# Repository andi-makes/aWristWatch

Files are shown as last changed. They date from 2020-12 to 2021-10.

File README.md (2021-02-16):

# andi makes a wrist watch! ⌚
> *It ain't pretty, but it's **mine**!* 😄

## Hardware 💡
### Microcontroller
The microcontroller used by this project is the `STM32L011F4` from STM. 
It features many peripherals as well as low power operation features.

### Display
This watch displays the time using four `KCSA02-105` 7-Segment displays from 
Kingbright. They were chosen because of their small footprint. Those 7-Segment 
displays are driven by the `STP08DP05` serial constant current driver from STM.

### Power
In it's normal operation, the watch gets powered by a LIPO battery. It can also 
be powered by an external powersource which provides 5V. The external connection
is also used to charge the internal LIPO using a `MCP73831` charger IC from 
Microchip. For OR-ing those two power supplies together so that the battery
is not used for powering the circuit during charging two `LM66100` ideal diodes
are used. The resulting powerline gets regulated by a `TLV70033` linear voltage 
regulator. The resulting 3.3V are used to power the microcontroller. For the 
powersupply for the display the non regulated voltage is used.

## Firmware 🧠

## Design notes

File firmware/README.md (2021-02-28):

# About
I am using the following tools:
 - docker
 - arm-none-eabi-gcc
 - cmake and ccmake
 - ninja build system
 - cppcheck

`C++20` is the used `C++` standard.

# Build
```
[c]cmake -G Ninja -DCMAKE_TOOLCHAIN_FILE=cmake/toolchain.cmake PROJECTDIR
```
The resulting binary files will be located in the `bin` folder.

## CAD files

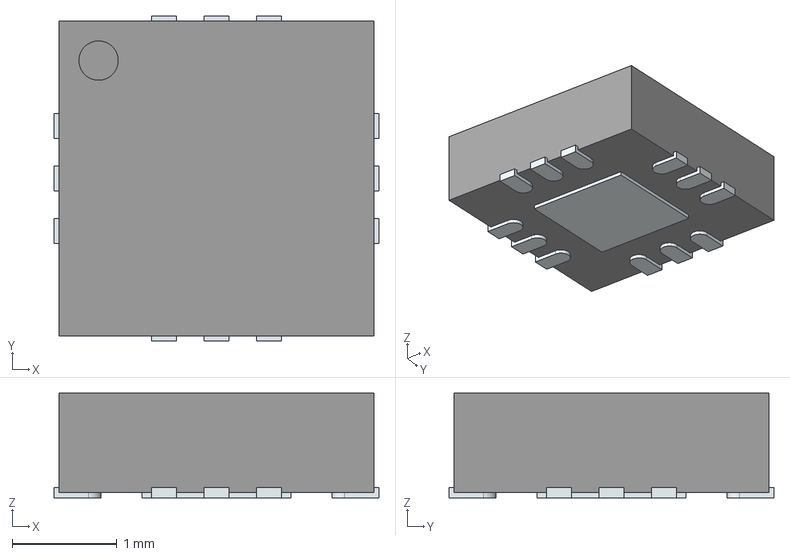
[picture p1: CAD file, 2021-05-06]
hardware/3dmodels/TCPP01-M12.stp
3.10 x 3.10 x 1.00 mm
ThermalPin
PinsArrayLR
PinsArrayTB

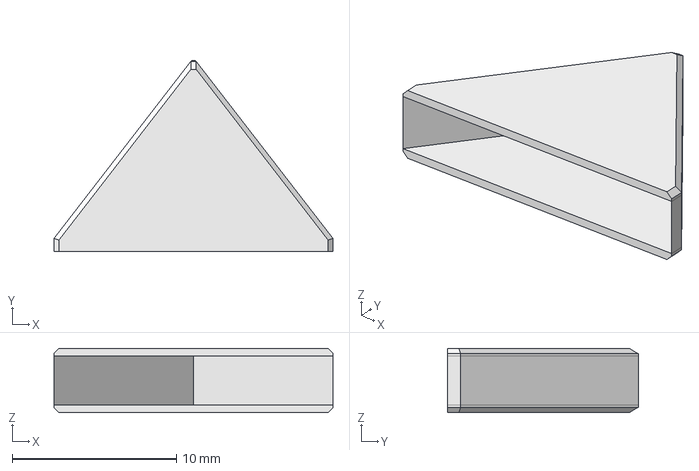
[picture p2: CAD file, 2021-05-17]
model/wristband_endcap.FCStd
17.0 x 11.6 x 3.90 mm

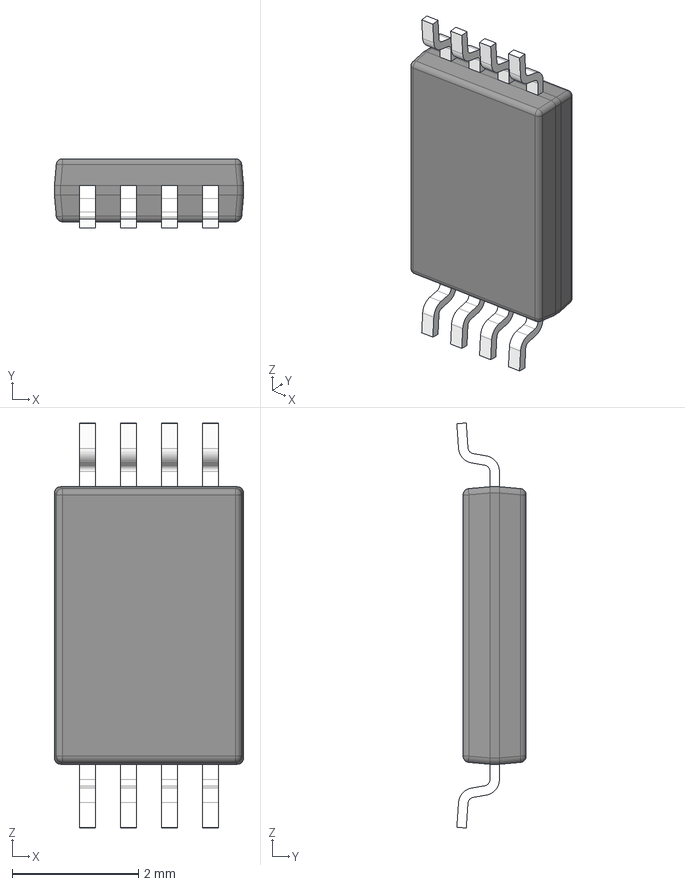
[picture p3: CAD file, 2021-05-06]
hardware/3dmodels/PW0008A.stp
3.00 x 1.10 x 6.42 mm
BODY-SO
LEAD-SO x 8
PIN1-ID

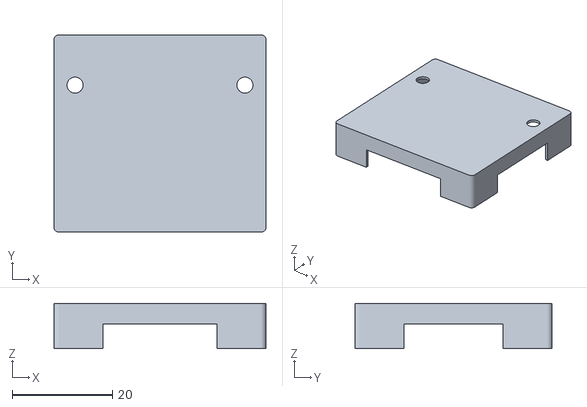
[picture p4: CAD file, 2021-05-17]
model/upper_no_prog.stl
42.3 x 39.4 x 9.00

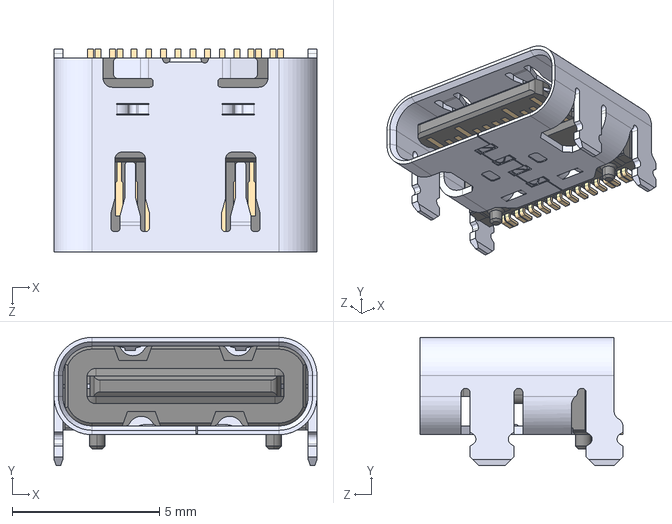
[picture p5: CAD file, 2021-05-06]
hardware/3dmodels/DX07S016JA1R1500--3DModel-STEP-1.STEP
8.94 x 4.36 x 6.90 mm

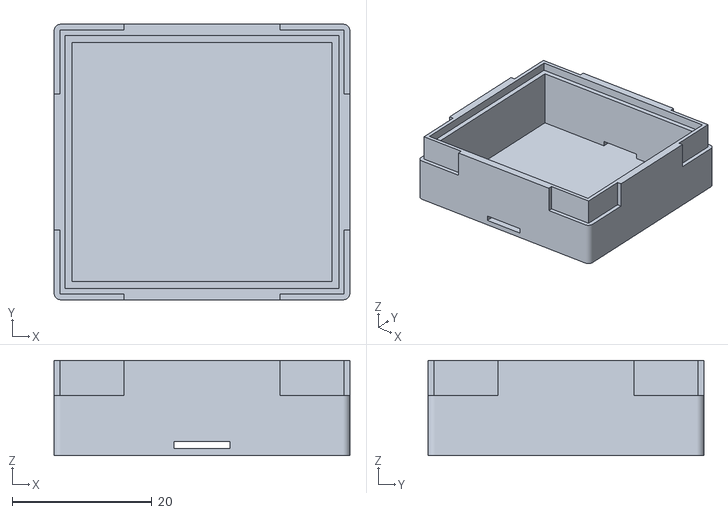
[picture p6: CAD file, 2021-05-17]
model/lower.stl
42.3 x 39.4 x 13.6

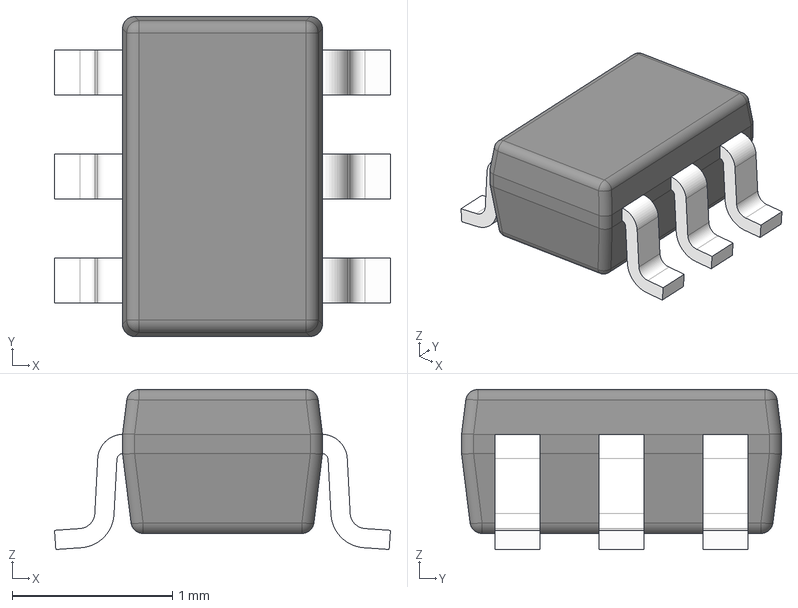
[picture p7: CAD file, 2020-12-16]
hardware/3dmodels/DCK0006A.stp
2.10 x 2.00 x 1.00 mm
BODY-SOT
LEAD-SOT x 6
PIN1-ID

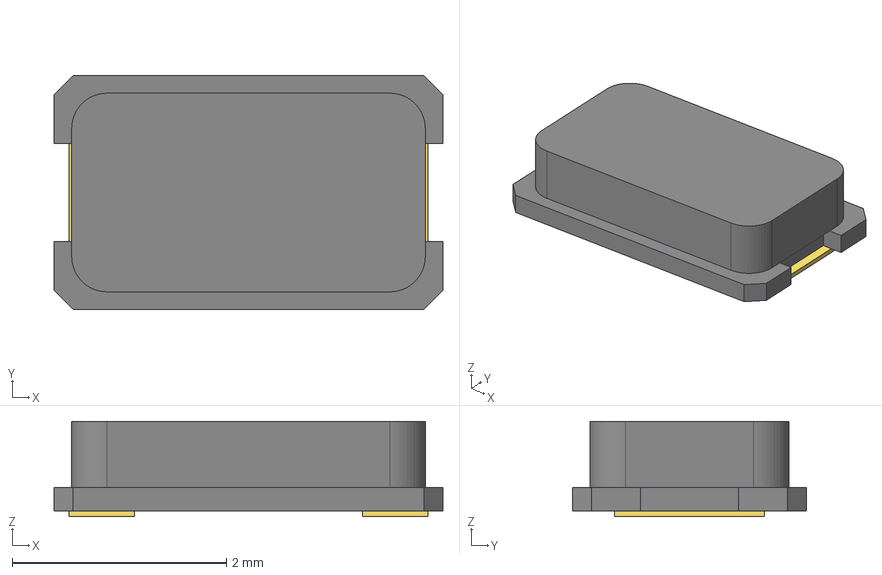
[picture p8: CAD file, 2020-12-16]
hardware/3dmodels/XTAL_ABS07-166-32_768KHZ-T_ABR.step
3.63 x 2.18 x 0.889 mm

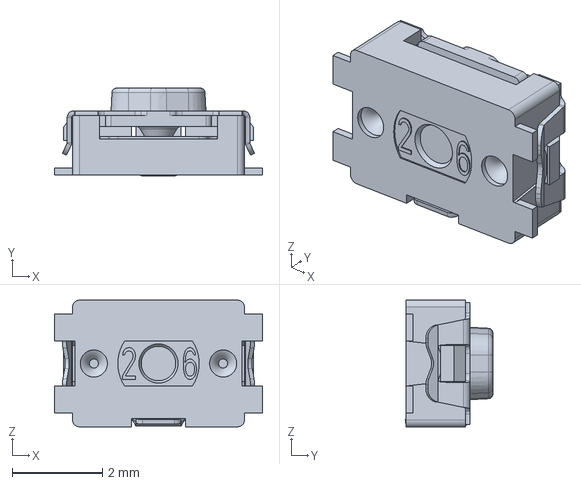
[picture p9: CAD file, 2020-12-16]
hardware/3dmodels/KMR211GLFS.stp
4.60 x 1.94 x 2.80 mm

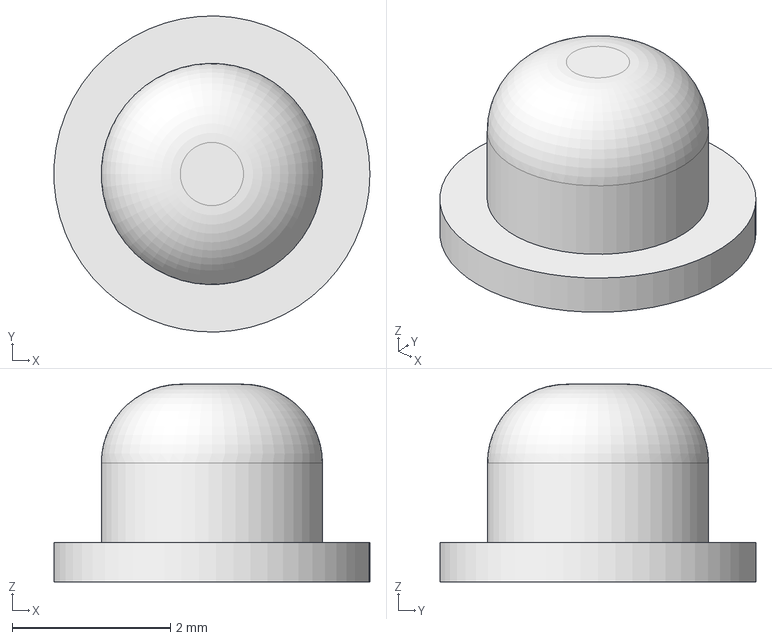
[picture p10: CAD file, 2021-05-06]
model/button.FCStd
4.00 x 4.00 x 2.50 mm

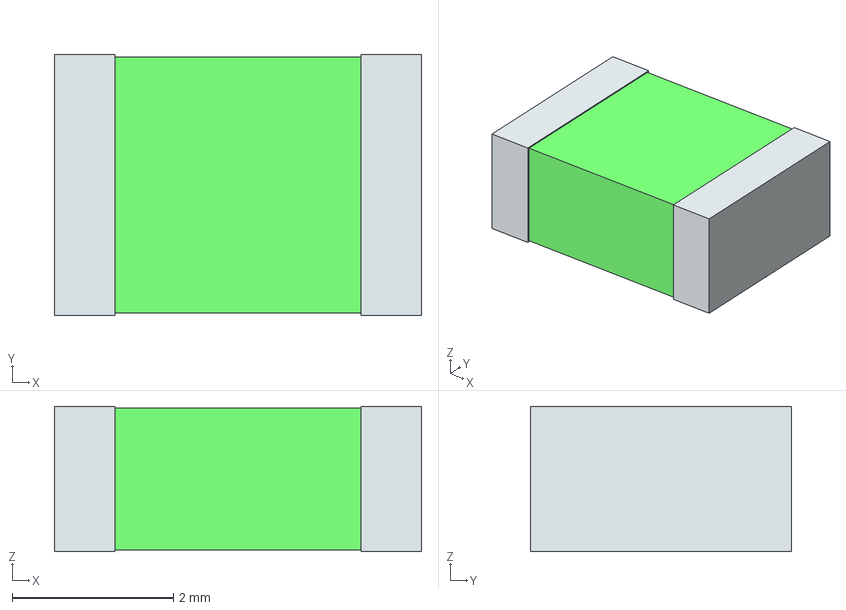
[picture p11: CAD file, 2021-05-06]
hardware/3dmodels/1812L050_60MR.stp
4.55 x 3.24 x 1.80 mm
term1
term2

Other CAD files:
model/wristband_endcap-cap.stl
model/case.FCStd
model/upper.stl
model/button.stl

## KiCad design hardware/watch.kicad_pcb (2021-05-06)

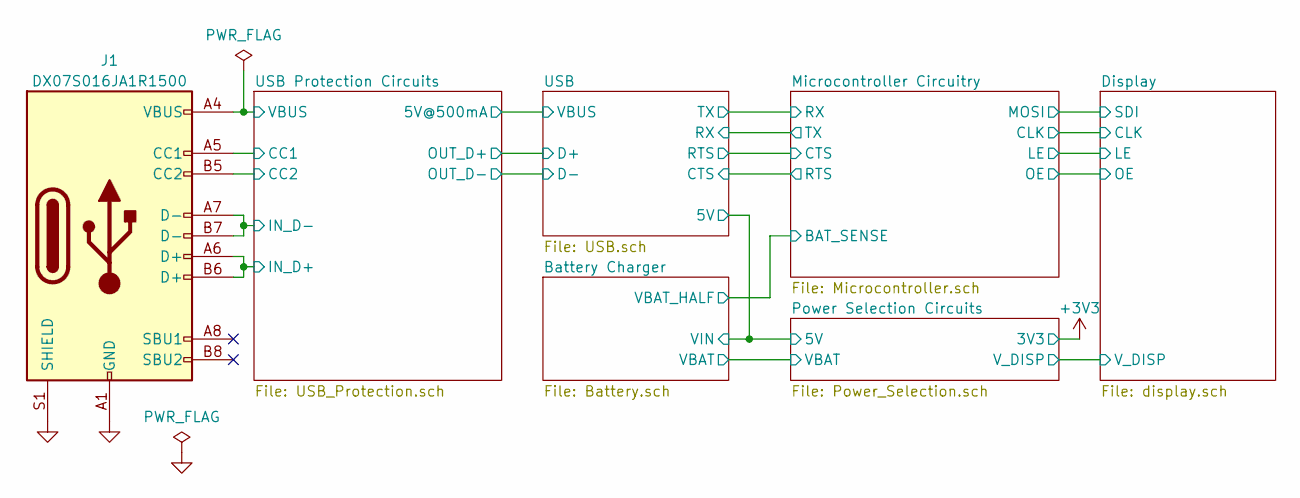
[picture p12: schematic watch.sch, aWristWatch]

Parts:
J1: DX07S016JA1R1500

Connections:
/USB Protection Circuits/CC1: J1.A5 (CC1); also elsewhere on the board
/USB Protection Circuits/CC2: J1.B5 (CC2); also elsewhere on the board
/USB Protection Circuits/IN_D+: J1.A6 (D+), J1.B6 (D+); also elsewhere on the board
/USB Protection Circuits/IN_D-: J1.A7 (D-), J1.B7 (D-); also elsewhere on the board
/USB Protection Circuits/VBUS: J1.A4 (VBUS), J1.A9 (VBUS), J1.B4 (VBUS), J1.B9 (VBUS); also elsewhere on the board
GND: J1.A1 (GND), J1.A12 (GND), J1.B1 (GND), J1.B12 (GND), J1.S1 (SHIELD); also elsewhere on the board

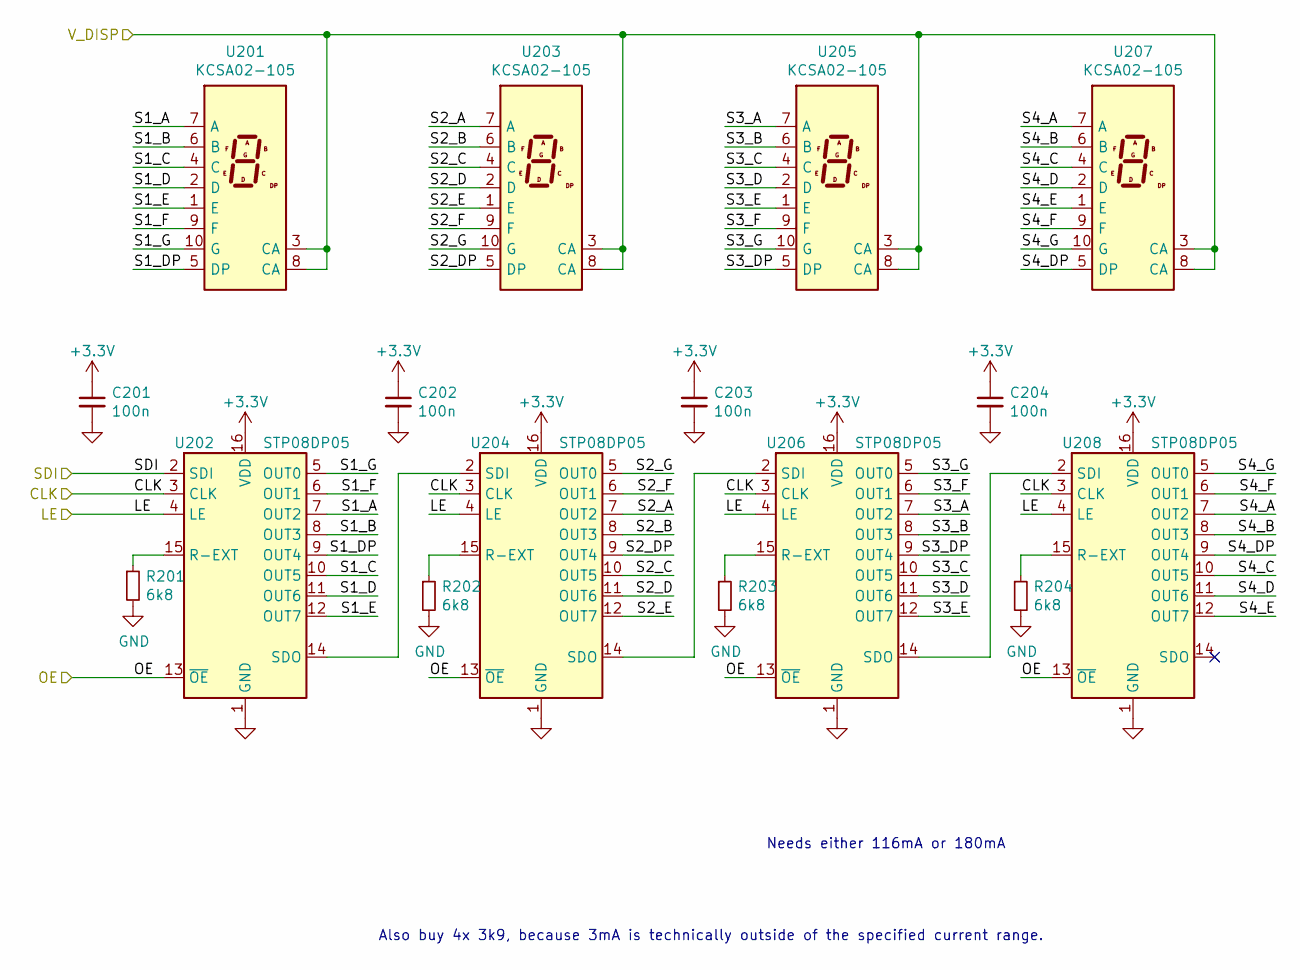
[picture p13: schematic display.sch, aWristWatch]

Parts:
C201, C202, C203, C204: 100n; C_0603_1608Metric
R201, R202, R203, R204: 6k8; R_0603_1608Metric
U201, U203, U205, U207: KCSA02-105; KCSC02-105
U202, U204, U206, U208: STP08DP05; TSSOP-16_4.4x5mm_P0.65mm; Part Number STP08DP05TTR

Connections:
+3V3: C201.1, C202.1, C203.1, C204.1, U202.16 (VDD), U204.16 (VDD), U206.16 (VDD), U208.16 (VDD); also elsewhere on the board
/Display/CLK: U202.3 (CLK), U204.3 (CLK), U206.3 (CLK), U208.3 (CLK); also elsewhere on the board
/Display/LE: U202.4 (LE), U204.4 (LE), U206.4 (LE), U208.4 (LE); also elsewhere on the board
/Display/OE: U202.13 (~OE), U204.13 (~OE), U206.13 (~OE), U208.13 (~OE); also elsewhere on the board
/Display/S1_A: U201.7 (A), U202.7 (OUT2)
/Display/S1_B: U201.6 (B), U202.8 (OUT3)
/Display/S1_C: U201.4 (C), U202.10 (OUT5)
/Display/S1_D: U201.2 (D), U202.11 (OUT6)
/Display/S1_DP: U201.5 (DP), U202.9 (OUT4)
/Display/S1_E: U201.1 (E), U202.12 (OUT7)
/Display/S1_F: U201.9 (F), U202.6 (OUT1)
/Display/S1_G: U201.10 (G), U202.5 (OUT0)
/Display/S2_A: U203.7 (A), U204.7 (OUT2)
/Display/S2_B: U203.6 (B), U204.8 (OUT3)
/Display/S2_C: U203.4 (C), U204.10 (OUT5)
/Display/S2_D: U203.2 (D), U204.11 (OUT6)
/Display/S2_DP: U203.5 (DP), U204.9 (OUT4)
/Display/S2_E: U203.1 (E), U204.12 (OUT7)
/Display/S2_F: U203.9 (F), U204.6 (OUT1)
/Display/S2_G: U203.10 (G), U204.5 (OUT0)
/Display/S3_A: U205.7 (A), U206.7 (OUT2)
/Display/S3_B: U205.6 (B), U206.8 (OUT3)
/Display/S3_C: U205.4 (C), U206.10 (OUT5)
/Display/S3_D: U205.2 (D), U206.11 (OUT6)
/Display/S3_DP: U205.5 (DP), U206.9 (OUT4)
/Display/S3_E: U205.1 (E), U206.12 (OUT7)
/Display/S3_F: U205.9 (F), U206.6 (OUT1)
/Display/S3_G: U205.10 (G), U206.5 (OUT0)
/Display/S4_A: U207.7 (A), U208.7 (OUT2)
/Display/S4_B: U207.6 (B), U208.8 (OUT3)
/Display/S4_C: U207.4 (C), U208.10 (OUT5)
/Display/S4_D: U207.2 (D), U208.11 (OUT6)
/Display/S4_DP: U207.5 (DP), U208.9 (OUT4)
/Display/S4_E: U207.1 (E), U208.12 (OUT7)
/Display/S4_F: U207.9 (F), U208.6 (OUT1)
/Display/S4_G: U207.10 (G), U208.5 (OUT0)
/Display/V_DISP: U201.3 (CA), U201.8 (CA), U203.3 (CA), U203.8 (CA), U205.3 (CA), U205.8 (CA), U207.3 (CA), U207.8 (CA); also elsewhere on the board
/Microcontroller Circuitry/MOSI: U202.2 (SDI); also elsewhere on the board
GND: C201.2, C202.2, C203.2, C204.2, R201.2, R202.2, R203.2, R204.2, U202.1 (GND), U204.1 (GND), U206.1 (GND), U208.1 (GND); also elsewhere on the board
unnamed: R201.1, U202.15 (R-EXT)
unnamed: R202.1, U204.15 (R-EXT)
unnamed: R203.1, U206.15 (R-EXT)
unnamed: R204.1, U208.15 (R-EXT)
unnamed: U202.14 (SDO), U204.2 (SDI)
unnamed: U204.14 (SDO), U206.2 (SDI)
unnamed: U206.14 (SDO), U208.2 (SDI)

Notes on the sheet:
Also buy 4x 3k9, because 3mA is technically outside of the specified current range.
Needs either 116mA or 180mA

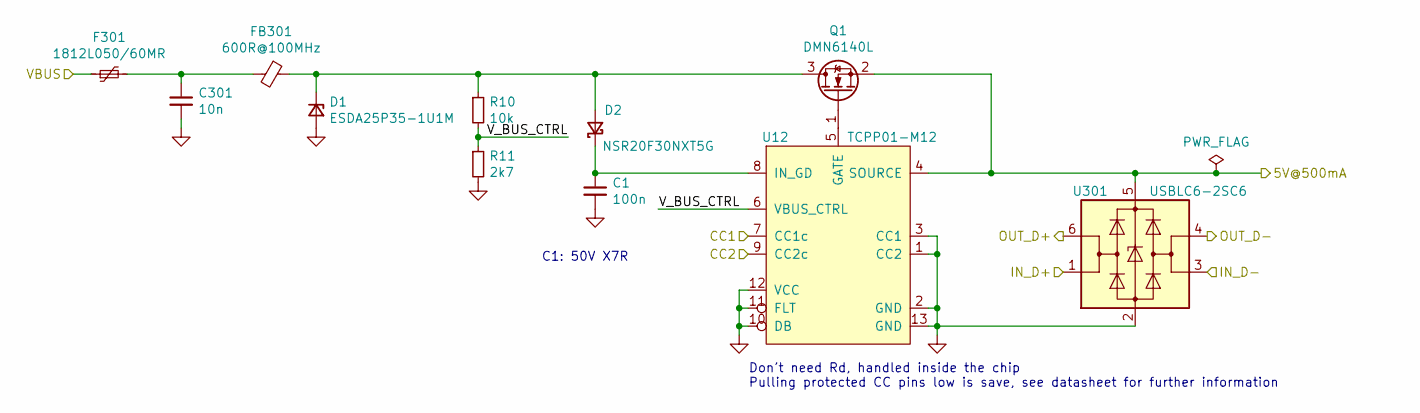
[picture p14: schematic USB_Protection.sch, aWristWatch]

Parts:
C1: 100n; C_0603_1608Metric
C301: 10n; C_0603_1608Metric
D1: ESDA25P35-1U1M; D_0603_1608Metric
D2: NSR20F30NXT5G; D_0603_1608Metric
F301: 1812L050/60MR; Fuse_1812_4532Metric
FB301: 600R@100MHz; L_0603_1608Metric
Q1: DMN6140L; SOT-23
R10: 10k; R_0603_1608Metric
R11: 2k7; R_0603_1608Metric
U12: TCPP01-M12; QFN-12-1EP_3x3mm_P0.51mm_EP1.45x1.45mm
U301: USBLC6-2SC6; SOT-23-6

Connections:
/USB Protection Circuits/5V@500mA: Q1.2 (S), U12.4 (SOURCE), U301.5 (VBUS); also elsewhere on the board
/USB Protection Circuits/CC1: U12.7 (CC1c); also elsewhere on the board
/USB Protection Circuits/CC2: U12.9 (CC2c); also elsewhere on the board
/USB Protection Circuits/IN_D+: U301.1 (I/O1); also elsewhere on the board
/USB Protection Circuits/IN_D-: U301.3 (I/O2); also elsewhere on the board
/USB Protection Circuits/VBUS: F301.1; also elsewhere on the board
/USB Protection Circuits/V_BUS_CTRL: R10.2, R11.1, U12.6 (VBUS_CTRL)
/USB/D+: U301.6 (I/O1); also elsewhere on the board
/USB/D-: U301.4 (I/O2); also elsewhere on the board
GND: C1.2, C301.2, D1.2 (A), R11.2, U12.1 (CC2), U12.2 (GND), U12.3 (CC1), U12.10 (DB), U12.11 (FLT), U12.12 (VCC), U12.13 (GND), U301.2 (GND); also elsewhere on the board
unnamed: C1.1, D2.1 (K), U12.8 (IN_GD)
unnamed: C301.1, F301.2, FB301.2
unnamed: D1.1 (K), D2.2 (A), FB301.1, Q1.3 (D), R10.1
unnamed: Q1.1 (G), U12.5 (GATE)

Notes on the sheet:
Don't need Rd, handled inside the chip Pulling protected CC pins low is save, see datasheet for further information
C1: 50V X7R

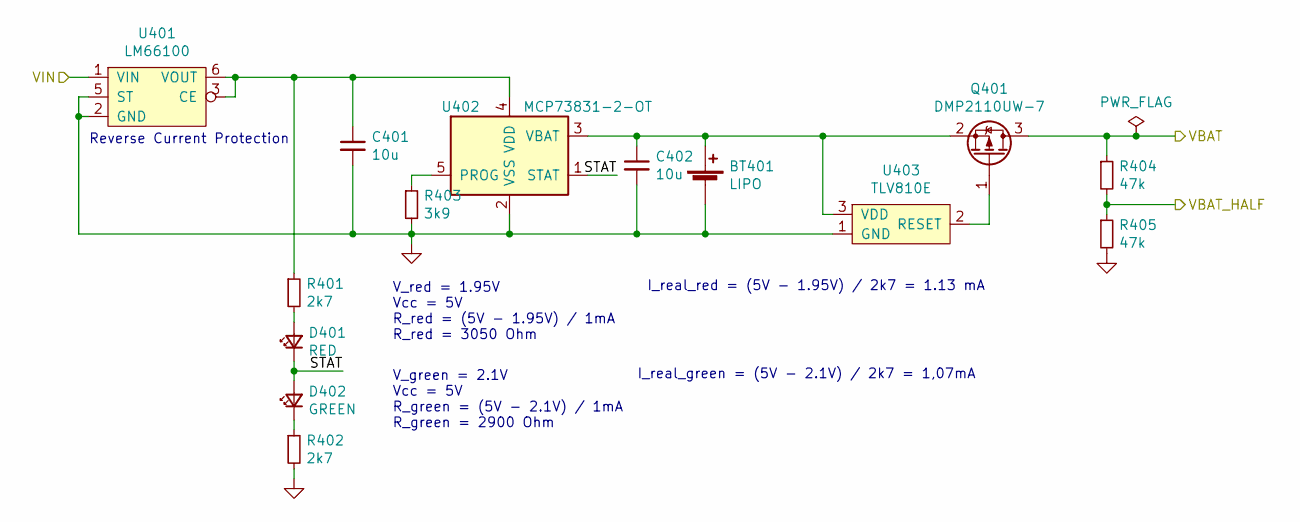
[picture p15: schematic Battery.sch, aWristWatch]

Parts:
BT401: LIPO; PinHeader_1x02_P2.54mm_Vertical
C401, C402: 10u; C_0805_2012Metric
D401: RED; LED_0603_1608Metric; Part Number AA1608SURSK
D402: GREEN; LED_0603_1608Metric; Part Number AA1608CGSK
Q401: DMP2110UW-7; SOT-323_SC-70
R401, R402: 2k7; R_0603_1608Metric
R403: 3k9; R_0603_1608Metric
R404, R405: 47k; R_0603_1608Metric
U401: LM66100; Sc70-6
U402: MCP73831-2-OT; SOT-23-5
U403: TLV810E; SOT-23

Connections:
/Battery Charger/STAT: D401.1 (K), D402.2 (A), U402.1 (STAT)
/Battery Charger/VBAT: Q401.3 (D), R404.1; also elsewhere on the board
/Microcontroller Circuitry/BAT_SENSE: R404.2, R405.1; also elsewhere on the board
/Power Selection Circuits/5V: U401.1 (VIN); also elsewhere on the board
GND: BT401.2 (-), C401.2, C402.2, R402.2, R403.2, R405.2, U401.2 (GND), U401.5 (ST), U402.2 (VSS), U403.1 (GND); also elsewhere on the board
unnamed: BT401.1 (+), C402.1, Q401.2 (S), U402.3 (VBAT), U403.3 (VDD)
unnamed: C401.1, R401.1, U401.3 (CE), U401.6 (VOUT), U402.4 (VDD)
unnamed: D401.2 (A), R401.2
unnamed: D402.1 (K), R402.1
unnamed: Q401.1 (G), U403.2 (RESET)
unnamed: R403.1, U402.5 (PROG)

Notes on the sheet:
Reverse Current Protection
V_red = 1.95V Vcc = 5V R_red = (5V - 1.95V) / 1mA R_red = 3050 Ohm
V_green = 2.1V Vcc = 5V R_green = (5V - 2.1V) / 1mA R_green = 2900 Ohm
I_real_red = (5V - 1.95V) / 2k7 = 1.13 mA
I_real_green = (5V - 2.1V) / 2k7 = 1,07mA

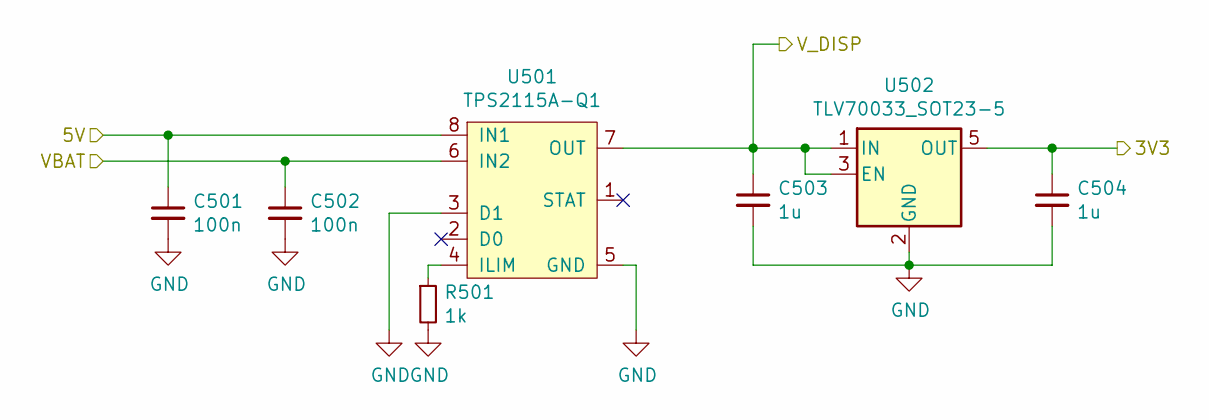
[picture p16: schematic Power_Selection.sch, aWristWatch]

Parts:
C501, C502: 100n; C_0603_1608Metric
C503, C504: 1u; C_0603_1608Metric
R501: 1k; R_0603_1608Metric
U501: TPS2115A-Q1; TSSOP-8_3x6.4_P0.65mm
U502: TLV70033_SOT23-5; SOT-23-5

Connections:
+3V3: C504.1, U502.5 (OUT); also elsewhere on the board
/Battery Charger/VBAT: C502.1, U501.6 (IN2); also elsewhere on the board
/Display/V_DISP: C503.1, U501.7 (OUT), U502.1 (IN), U502.3 (EN); also elsewhere on the board
/Power Selection Circuits/5V: C501.1, U501.8 (IN1); also elsewhere on the board
GND: C501.2, C502.2, C503.2, C504.2, R501.2, U501.3 (D1), U501.5 (GND), U502.2 (GND); also elsewhere on the board
unnamed: R501.1, U501.4 (ILIM)

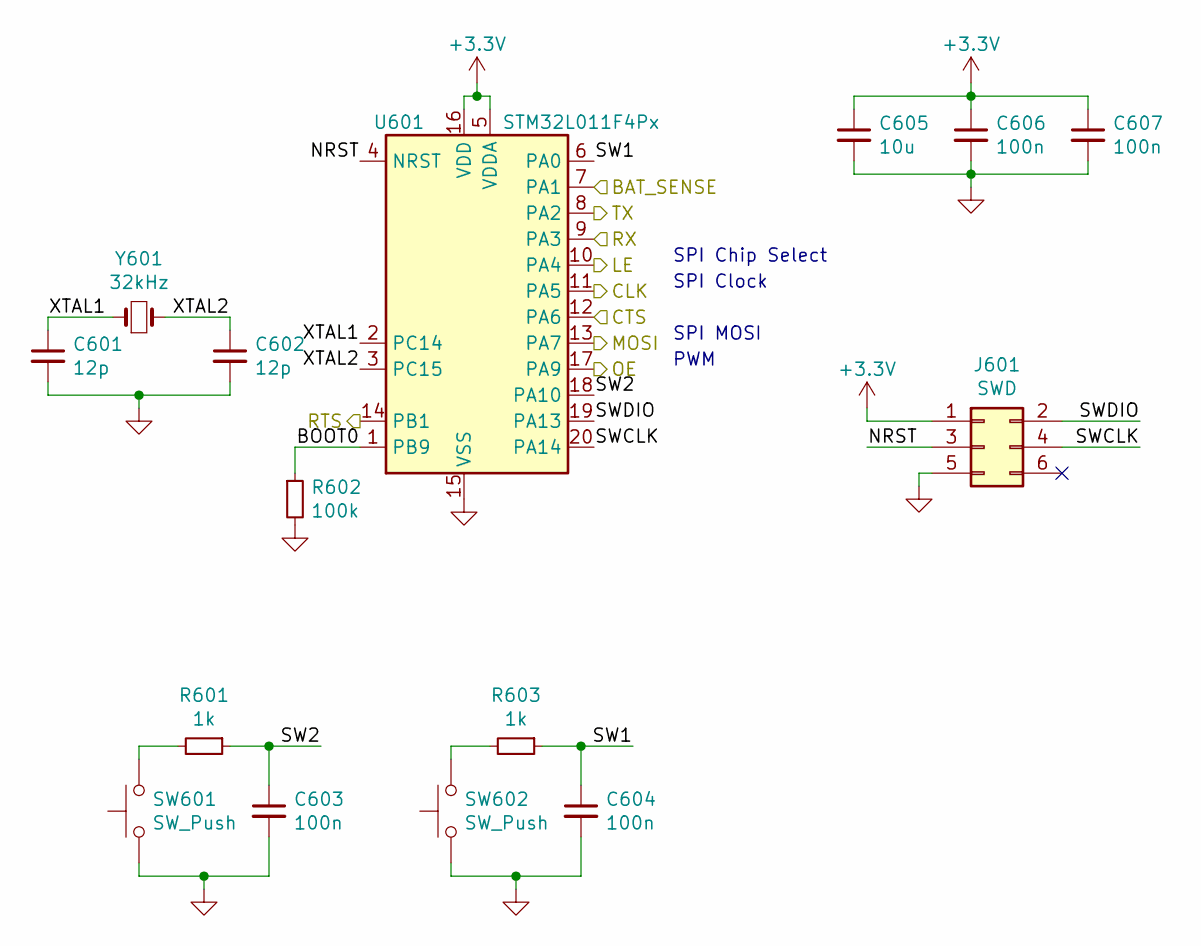
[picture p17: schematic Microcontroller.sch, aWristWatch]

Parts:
C601, C602: 12p; C_0603_1608Metric
C603, C604, C606, C607: 100n; C_0603_1608Metric
C605: 10u; C_0805_2012Metric
J601: SWD; Tag-Connect_TC2030-IDC-NL_2x03_P1.27mm_Vertical
R601, R603: 1k; R_0603_1608Metric
R602: 100k; R_0603_1608Metric
SW601, SW602: SW_Push; SW_Push_1P1T_NO_CK_KMR2
U601: STM32L011F4Px; TSSOP-20_4.4x6.5mm_P0.65mm
Y601: 32kHz; Crystal_SMD_3215-2Pin_3.2x1.5mm

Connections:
+3V3: C605.1, C606.1, C607.1, J601.1, U601.5 (VDDA), U601.16 (VDD); also elsewhere on the board
/Display/CLK: U601.11 (PA5); also elsewhere on the board
/Display/LE: U601.10 (PA4); also elsewhere on the board
/Display/OE: U601.17 (PA9); also elsewhere on the board
/Microcontroller Circuitry/BAT_SENSE: U601.7 (PA1); also elsewhere on the board
/Microcontroller Circuitry/BOOT0: R602.1, U601.1 (PB9)
/Microcontroller Circuitry/CTS: U601.12 (PA6); also elsewhere on the board
/Microcontroller Circuitry/MOSI: U601.13 (PA7); also elsewhere on the board
/Microcontroller Circuitry/NRST: J601.3, U601.4 (NRST)
/Microcontroller Circuitry/RX: U601.9 (PA3); also elsewhere on the board
/Microcontroller Circuitry/SW1: C604.1, R603.1, U601.6 (PA0)
/Microcontroller Circuitry/SW2: C603.1, R601.1, U601.18 (PA10)
/Microcontroller Circuitry/SWCLK: J601.4, U601.20 (PA14)
/Microcontroller Circuitry/SWDIO: J601.2, U601.19 (PA13)
/Microcontroller Circuitry/XTAL1: C601.1, U601.2 (PC14), Y601.1
/Microcontroller Circuitry/XTAL2: C602.1, U601.3 (PC15), Y601.2
/USB/CTS: U601.14 (PB1); also elsewhere on the board
/USB/RX: U601.8 (PA2); also elsewhere on the board
GND: C601.2, C602.2, C603.2, C604.2, C605.2, C606.2, C607.2, J601.5, R602.2, SW601.1, SW602.1, U601.15 (VSS); also elsewhere on the board
unnamed: R601.2, SW601.2
unnamed: R603.2, SW602.2

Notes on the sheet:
SPI Chip Select
SPI Clock
SPI MOSI
PWM

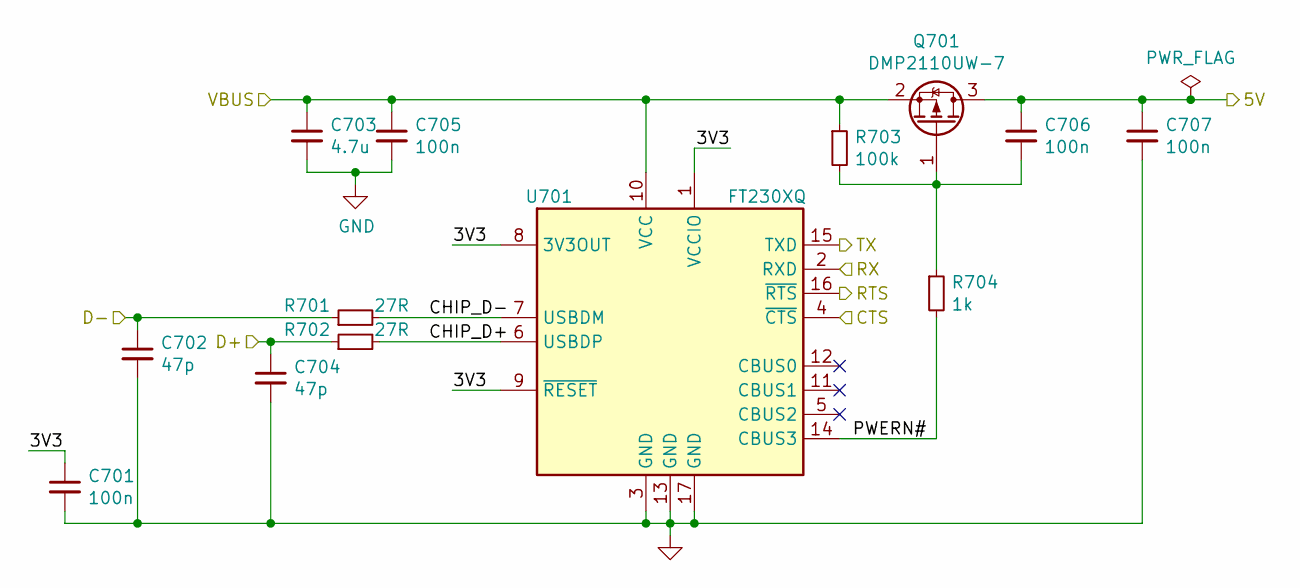
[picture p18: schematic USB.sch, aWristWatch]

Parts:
C701, C705, C706, C707: 100n; C_0603_1608Metric
C702, C704: 47p; C_0603_1608Metric
C703: 4.7u; C_0805_2012Metric
Q701: DMP2110UW-7; SOT-323_SC-70
R701, R702: 27R; R_0603_1608Metric
R703: 100k; R_0603_1608Metric
R704: 1k; R_0603_1608Metric
U701: FT230XQ; QFN-16-1EP_4x4mm_P0.65mm_EP2.1x2.1mm

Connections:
/Microcontroller Circuitry/CTS: U701.16 (~RTS); also elsewhere on the board
/Microcontroller Circuitry/RX: U701.15 (TXD); also elsewhere on the board
/Power Selection Circuits/5V: C706.1, C707.1, Q701.3 (D); also elsewhere on the board
/USB Protection Circuits/5V@500mA: C703.1, C705.1, Q701.2 (S), R703.1, U701.10 (VCC); also elsewhere on the board
/USB/3V3: C701.1, U701.1 (VCCIO), U701.8 (3V3OUT), U701.9 (~RESET)
/USB/CHIP_D+: R702.2, U701.6 (USBDP)
/USB/CHIP_D-: R701.2, U701.7 (USBDM)
/USB/CTS: U701.4 (~CTS); also elsewhere on the board
/USB/D+: C704.1, R702.1; also elsewhere on the board
/USB/D-: C702.1, R701.1; also elsewhere on the board
/USB/PWERN#: R704.2, U701.14 (CBUS3)
/USB/RX: U701.2 (RXD); also elsewhere on the board
GND: C701.2, C702.2, C703.2, C704.2, C705.2, C707.2, U701.3 (GND), U701.13 (GND), U701.17 (GND); also elsewhere on the board
unnamed: C706.2, Q701.1 (G), R703.2, R704.1

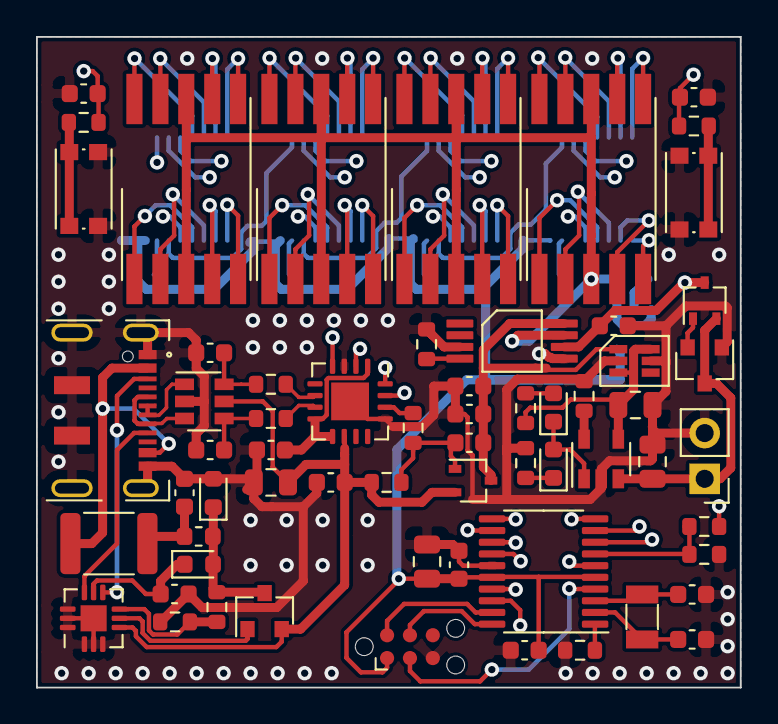
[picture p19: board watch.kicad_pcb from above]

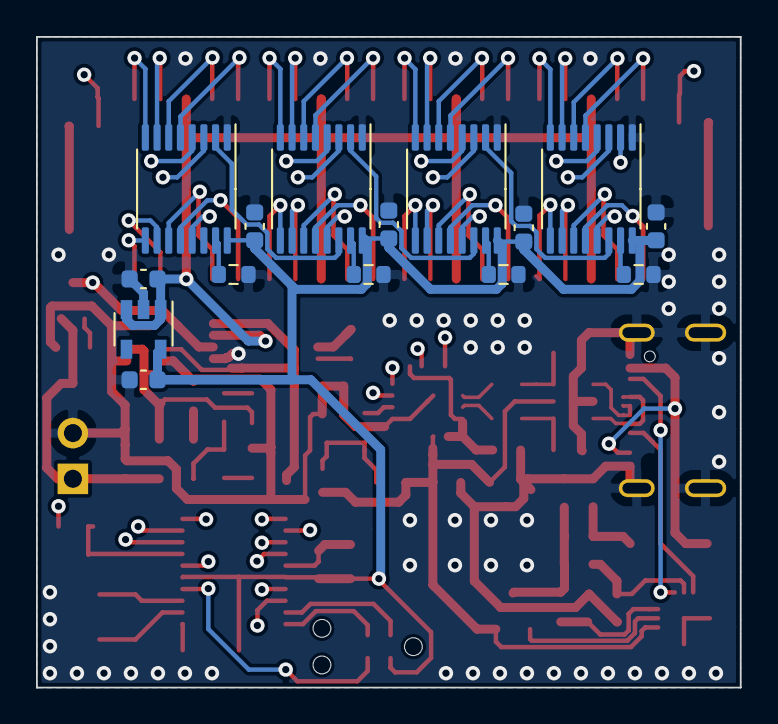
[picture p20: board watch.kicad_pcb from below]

Board: 4 copper layers, 39.1 x 36.1 mm, 77 parts (15 on the bottom side), 89 nets.

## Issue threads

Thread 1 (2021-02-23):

Code Qualität

kegelsknight, 2021-02-23:
* Initialisation von variablen sollte durch ``{}`` geschehen und nicht durch ``=``
* Globale Variablen und Funktionen in main.cpp, außer ``main()`` sollten in eigene Klasse und Dateipaar geschoben werden.
* main.cpp#360 ``if (!RTC::is_initialized())`` anstelle von == false.

Abgesehen davon solltest du noch eine README erstellen.

Closed 2021-03-01.

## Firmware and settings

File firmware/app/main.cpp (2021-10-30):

#include "driver/bat.hpp"
#include "driver/display.hpp"
#include "driver/input.hpp"
#include "sm.hpp"
#include "util/stby.hpp"

#include <chip/gpio.hpp>
#include <chip/interrupts.hpp>
#include <chip/pwr.hpp>
#include <chip/rtc.hpp>
#include <chip/spi.hpp>
#include <chip/syscfg.hpp>

// cppcheck-suppress unusedFunction
void SystemInit() {
    SYSCFG::power_on();
    RTC::power_on();
    SPI1::power_on();
    GPIOA::power_on();
}

int main() {
    RTC::enable();

    if (!RTC::is_initialized()) {
        aww::sm::set_state(aww::sm::STATE::EDIT_HRS);
        RTC::set_time_and_date(0, 0, 0, 1, 1, 0x21);
    }

    // RTC Wakup Timer, 0.125sec
    RTC::setup_wakeup_timer(255, 0);

    battery::setup();
    display::setup();
    input::setup();

    // Setup Stop mode
    using SCR = zol::reg<uint32_t, 0xE000ED10>;
    PWR::CR::set_bit(uint8_t(PWR::cr::LPSDSR));

    interrupt::enable();

    if (RTC::isr::WUTF::read()) {
        RTC::isr::WUTF::clear();
    }

    while (true) {
        if (aww::stby::in_stby()) {
//            using SCR = zol::reg<uint32_t, 0xE000ED10>;
            SCR::or_reg(1 << 2);                          // Set sleepdeep bit
            PWR::CR::set_bit(uint8_t(PWR::cr::CWWUF));    // Clear WUF bit
            PWR::CR::clear_bit(1U);                       // Clear PDDS Bit
            RCC::cfgr::STOPWUCK::write(false);            // MSI as wakeup clock

            RTC::disable_write_protect();
            RTC::cr::WUTIE::write(off);
            RTC::cr::WUTE::write(off);
            // RTC::cr::WUTE::write(off); // Disable Wakup Timer
            while (RTC::isr::WUTWF::read() == 0) {    // WUTWF
            }    // Make sure there is no interrupt pending
            asm("wfi");
            RTC::cr::WUTE::write(on);
            RTC::cr::WUTIE::write(on);
            RTC::enable_write_protect();
        }
    }
}

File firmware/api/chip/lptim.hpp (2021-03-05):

#pragma once

#include "register.hpp"

#include <cstdint>

namespace lptim {
    enum class isr : uint8_t {
        CMPM    = 0,
        ARRM    = 1,
        EXTTRIG = 2,
        CMPOK   = 3,
        ARROK   = 4,
        UP      = 5,
        DOWN    = 6
    };

    enum class icr : uint8_t {
        CMPMCF    = 0,
        ARRMCF    = 1,
        EXTTRIGCF = 2,
        CMPOKCF   = 3,
        ARROKCF   = 4,
        UPCF      = 5,
        DOWNCF    = 6
    };

    enum class ier : uint8_t {
        CMPMIE    = 0,
        ARRMIE    = 1,
        EXTTRIGIE = 2,
        CMPOKIE   = 3,
        ARROKIE   = 4,
        UPIE      = 5,
        DOWNIE    = 6
    };

    enum class cfgr : uint8_t {
        CKSEL     = 0,
        TIMOUT    = 19,
        WAVE      = 20,
        WAVEPOL   = 21,
        PRELOAD   = 22,
        COUNTMODE = 23,
        ENC       = 24
    };

    enum class trigen : uint8_t {
        SOFTWARE = 0,
        RISING   = 1,
        FALLING  = 2,
        BOTH     = 3
    };

    enum class trigsel : uint8_t {
        EXT_TRIG0 = 0,
        EXT_TRIG1 = 1,
        EXT_TRIG2 = 2,
        EXT_TRIG3 = 3,
        EXT_TRIG4 = 4,
        EXT_TRIG5 = 5,
        EXT_TRIG6 = 6,
        EXT_TRIG7 = 7
    };

    enum class presc : uint8_t {
        DIV_1   = 0,
        DIV_2   = 1,
        DIV_4   = 2,
        DIV_8   = 3,
        DIV_16  = 4,
        DIV_32  = 5,
        DIV_64  = 6,
        DIV_128 = 7
    };

    enum class trgflt : uint8_t {    // TODO: Fix this in .clang-format
        ANY   = 0,
        CLK_2 = 1,
        CLK_4 = 2,
        CLK_8 = 3
    };

    enum class ckflt : uint8_t {    //
        ANY   = 0,
        CLK_2 = 1,
        CLK_4 = 2,
        CLK_8 = 3
    };

    enum class ckpol : uint8_t {    //
        RISING_ENC1  = 0,
        FALLING_ENC2 = 1,
        BOTH_ENC3    = 2
    };

    enum class cr : uint8_t {    //
        ENABLE  = 0,
        SNGSTRT = 1,
        CNTSTRT = 2
    };

    enum class clock : uint8_t {    //
        APB   = 0,
        LS1   = 1,
        HSI16 = 2,
        LSE   = 3
    };
}

struct LPTIM1 {
    static constexpr zol::addr_t address = 0x4000'7C00;

    using ISR  = zol::reg<uint32_t, address + 0x0>;
    using ICR  = zol::reg<uint32_t, address + 0x4>;
    using IER  = zol::reg<uint32_t, address + 0x8>;
    using CFGR = zol::reg<uint32_t, address + 0xC>;
    using CR   = zol::reg<uint32_t, address + 0x10>;
    using CMP  = zol::reg<uint32_t, address + 0x14>;
    using ARR  = zol::reg<uint32_t, address + 0x18>;
    using CNT  = zol::reg<uint32_t, address + 0x1C>;

    static void power_on() { RCC::APB1ENR::set_bit(31U); }

    static void set_clock_source(lptim::clock c) {
        RCC::CCIPR::and_reg(~((0b11U) << 18));
        RCC::CCIPR::or_reg(static_cast<RCC::CCIPR::type_t>(c) << 18);
    }

    // TODO: implement get functions

    static bool get(lptim::isr i) {
        return ISR::get_bit(static_cast<unsigned int>(i));
    }

    static void clear_interrupt_pending(lptim::icr i) {
        ICR::set_bit(static_cast<unsigned int>(i));
    }

    static void set(lptim::ier i, bool b) {
        if (b) {
            IER::set_bit(static_cast<unsigned int>(i));
        } else {
            IER::clear_bit(static_cast<unsigned int>(i));
        }
    }

    static bool get(lptim::ier i) {
        return IER::get_bit(static_cast<unsigned int>(i));
    }

    static void set(lptim::cfgr bit, bool level) {
        if (level) {
            CFGR::set_bit(static_cast<unsigned int>(bit));
        } else {
            CFGR::clear_bit(static_cast<unsigned int>(bit));
        }
    }

    static bool get(lptim::cfgr bit) {
        return CFGR::get_bit(static_cast<unsigned int>(bit));
    }

    static void set(lptim::cr bit, bool level) {
        if (level) {
            CR::set_bit(static_cast<unsigned int>(bit));
        } else {
            CR::clear_bit(static_cast<unsigned int>(bit));
        }
    }

    static bool get(lptim::cr bit) {
        return CR::get_bit(static_cast<unsigned int>(bit));
    }

    static void set(lptim::trigen t) {
        CFGR::and_reg(~(0b11U << 17));
        CFGR::or_reg(static_cast<unsigned int>(t) << 17);
    }

    // TODO: If I ever need to read it, implement the function.
    // static lptim::trigen get(lptim::trigen) {
    // 	return (CFGR::get_reg() & (0b11 << 17)) >> 17;
    // }

    static void set(lptim::trigsel t) {
        CFGR::and_reg(~(0b111U << 13));
        CFGR::or_reg(static_cast<unsigned int>(t) << 13);
    }

    static void set(lptim::presc p) {
        CFGR::and_reg(~(0b111U << 9));
        CFGR::or_reg(static_cast<unsigned int>(p) << 9);
    }

    static void set(lptim::trgflt t) {
        CFGR::and_reg(~(0b11U << 6));
        CFGR::or_reg(static_cast<unsigned int>(t) << 6);
    }

    static void set(lptim::ckflt c) {
        CFGR::and_reg(~(0b11U << 3));
        CFGR::or_reg(static_cast<unsigned int>(c) << 3);
    }

    static void set(lptim::ckpol c) {
        CFGR::and_reg(~(0b11U << 1));
        CFGR::or_reg(static_cast<unsigned int>(c) << 1);
    }

    LPTIM1() = delete;
};

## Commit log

2020-09-26 added pcb to git
    [DCK0006A.stp, KMR211GLFS.stp, XTAL_ABS07-166-32_768KHZ-T_ABR-L.step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]
2020-12-16 hardware revision
    [DCK0006A.stp, KMR211GLFS.stp, XTAL_ABS07-166-32_768KHZ-T_ABR-L.step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]
2020-12-19 updated gpio and pin
2021-01-03 introduced interrupts.h
2021-01-10 added adc.h
2021-01-10 forgot to implement adc::enable
2021-01-15 initial battery indicator support
2021-01-17 introduced dma.h
2021-01-17 added some functionality to adc.h
2021-01-17 added battery.h Battery level menu now uses DMA :D
2021-01-17 update display driver
2021-02-01 case design
    [bottom.stl, case.FCStd, top.stl]
2021-02-05 updated firmware
    [watch-B_Cu.gbr, watch-B_Mask.gbr, watch-B_Paste.gbr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]
2021-02-05 case design files
    [bottom.stl, button.FCStd, button.stl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]
2021-02-14 updated case design
    [case.FCStd, case2.FCStd, lower2.stl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]
2021-02-14 included up-to-date hardware revision
    [watch-B_Cu.gbr, watch-B_Mask.gbr, watch-B_Paste.gbr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]
2021-02-16 new case iteration
    [case.FCStd, lower.stl, upper.stl]
2021-02-16 cleanup of files in model folder
    [bottom.stl, case2.FCStd, lower2.stl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]
2021-02-18 Added more warnings to build
    Added the Warning Flags `-Wextra`, `-pedantic` and fixed all warnings
    [lptim.h]
2021-02-21 rewrote adc algorithm
2021-02-27 Ignored bom file
2021-02-28 Better build (#2)
    * renamed .h files to hpp and cmake stuff
    * dockerfile
    * fixed errors from removing submodule
    * docker wip
    Added the propably simplest devcontainer vscode file
    Adapted Dockerfile to ubuntu:20.04
    cleaned up chip/stm32l011.cmake
    removed clangtidy and iwyu functionality from the cmake file
    Compiling in the container works.
    * Made Docker image slightly smaller
    * Added a README
    * removed lib folder
    * added build docker target
    [display.cpp]
2021-03-01 Issue 1 (#3)
    * #1.3
    * refactoring based on issue #1 point 2
    * More refactoring based on #1.2
    * refactoring based on #1.1
    * marked constructors of static only struct `delete`
    * refactoring
    * moved rtc_irqhandler into time.cpp
    Fixes #1
    [display.cpp]
2021-03-02 fixed all gcc warnings
    [display.cpp]
2021-03-04 Fixed all clang-tidy warnings except magic numbers
    [display.cpp]
2021-03-05 renamed `enable` functions to power_on introduced intrrupt::enable/disable
2021-05-06 Hw3 (#4)
    * working on hardware rev3
    * fixed usb type c cc pin termination
    * reverse current protection
    * hardware development
    * schematic should be done, pcb is next
    * wip hw
    * finished routing
    * calc current consumption
    * calculate current consumption
    * added 3d models
    * file cleanup
    * added some vias to gnd plane
    * added powerflags
    * minor improvements
    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
    [1812L050_60MR.stp, Battery.sch, DX07S016JA1R1500--3DModel-STEP-1.STEP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]
2021-05-08 fixed diplay off bug
    [display.cpp]
2021-05-08 fixed display glitching at higher brightness
    [display.cpp]
2021-05-17 modified case and wip endcap for wrist-band
    [case.FCStd, lower.stl, upper_no_prog.stl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]
